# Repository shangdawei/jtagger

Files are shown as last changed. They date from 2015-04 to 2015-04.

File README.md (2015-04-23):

# jtagger?

Well, it's not really just a jtagger, but I've been calling it that. It's also
been christened the Bit Quacker... uh, because it quacks? \*shrug\*

The basis for this design is sort of like the [Bus Blaster](http://dangerousprototypes.com/docs/Bus_Blaster), with a few nice mods. It's smaller (I'm working on V2, which may or may not ever be finished, which will be even smaller), it has an FPGA instead of a CPLD (not only more versatile, but will never be worn out by writes and rewrites), it's 5V-capable, and it can even do up to 13V on one pin, to enable programming microcontrollers with HVP.

The idea is that this can be adapted to program (as close to literally as possible) _any_ serial-programmed logic device, and debugging can be done as well.

In its most basic form, it's compatible with FT2232-compatible JTAG tools, as a simple firmware can be loaded to the FPGA that just passes the [MPSSE](http://www.ftdichip.com/Support/Documents/AppNotes/AN_135_MPSSE_Basics.pdf) signals straight through. The second port on the FT2232 can program the FPGA, so it's self-programming (it does, however, have a flash memory, so it can be preloaded with a firmware to skip this step).

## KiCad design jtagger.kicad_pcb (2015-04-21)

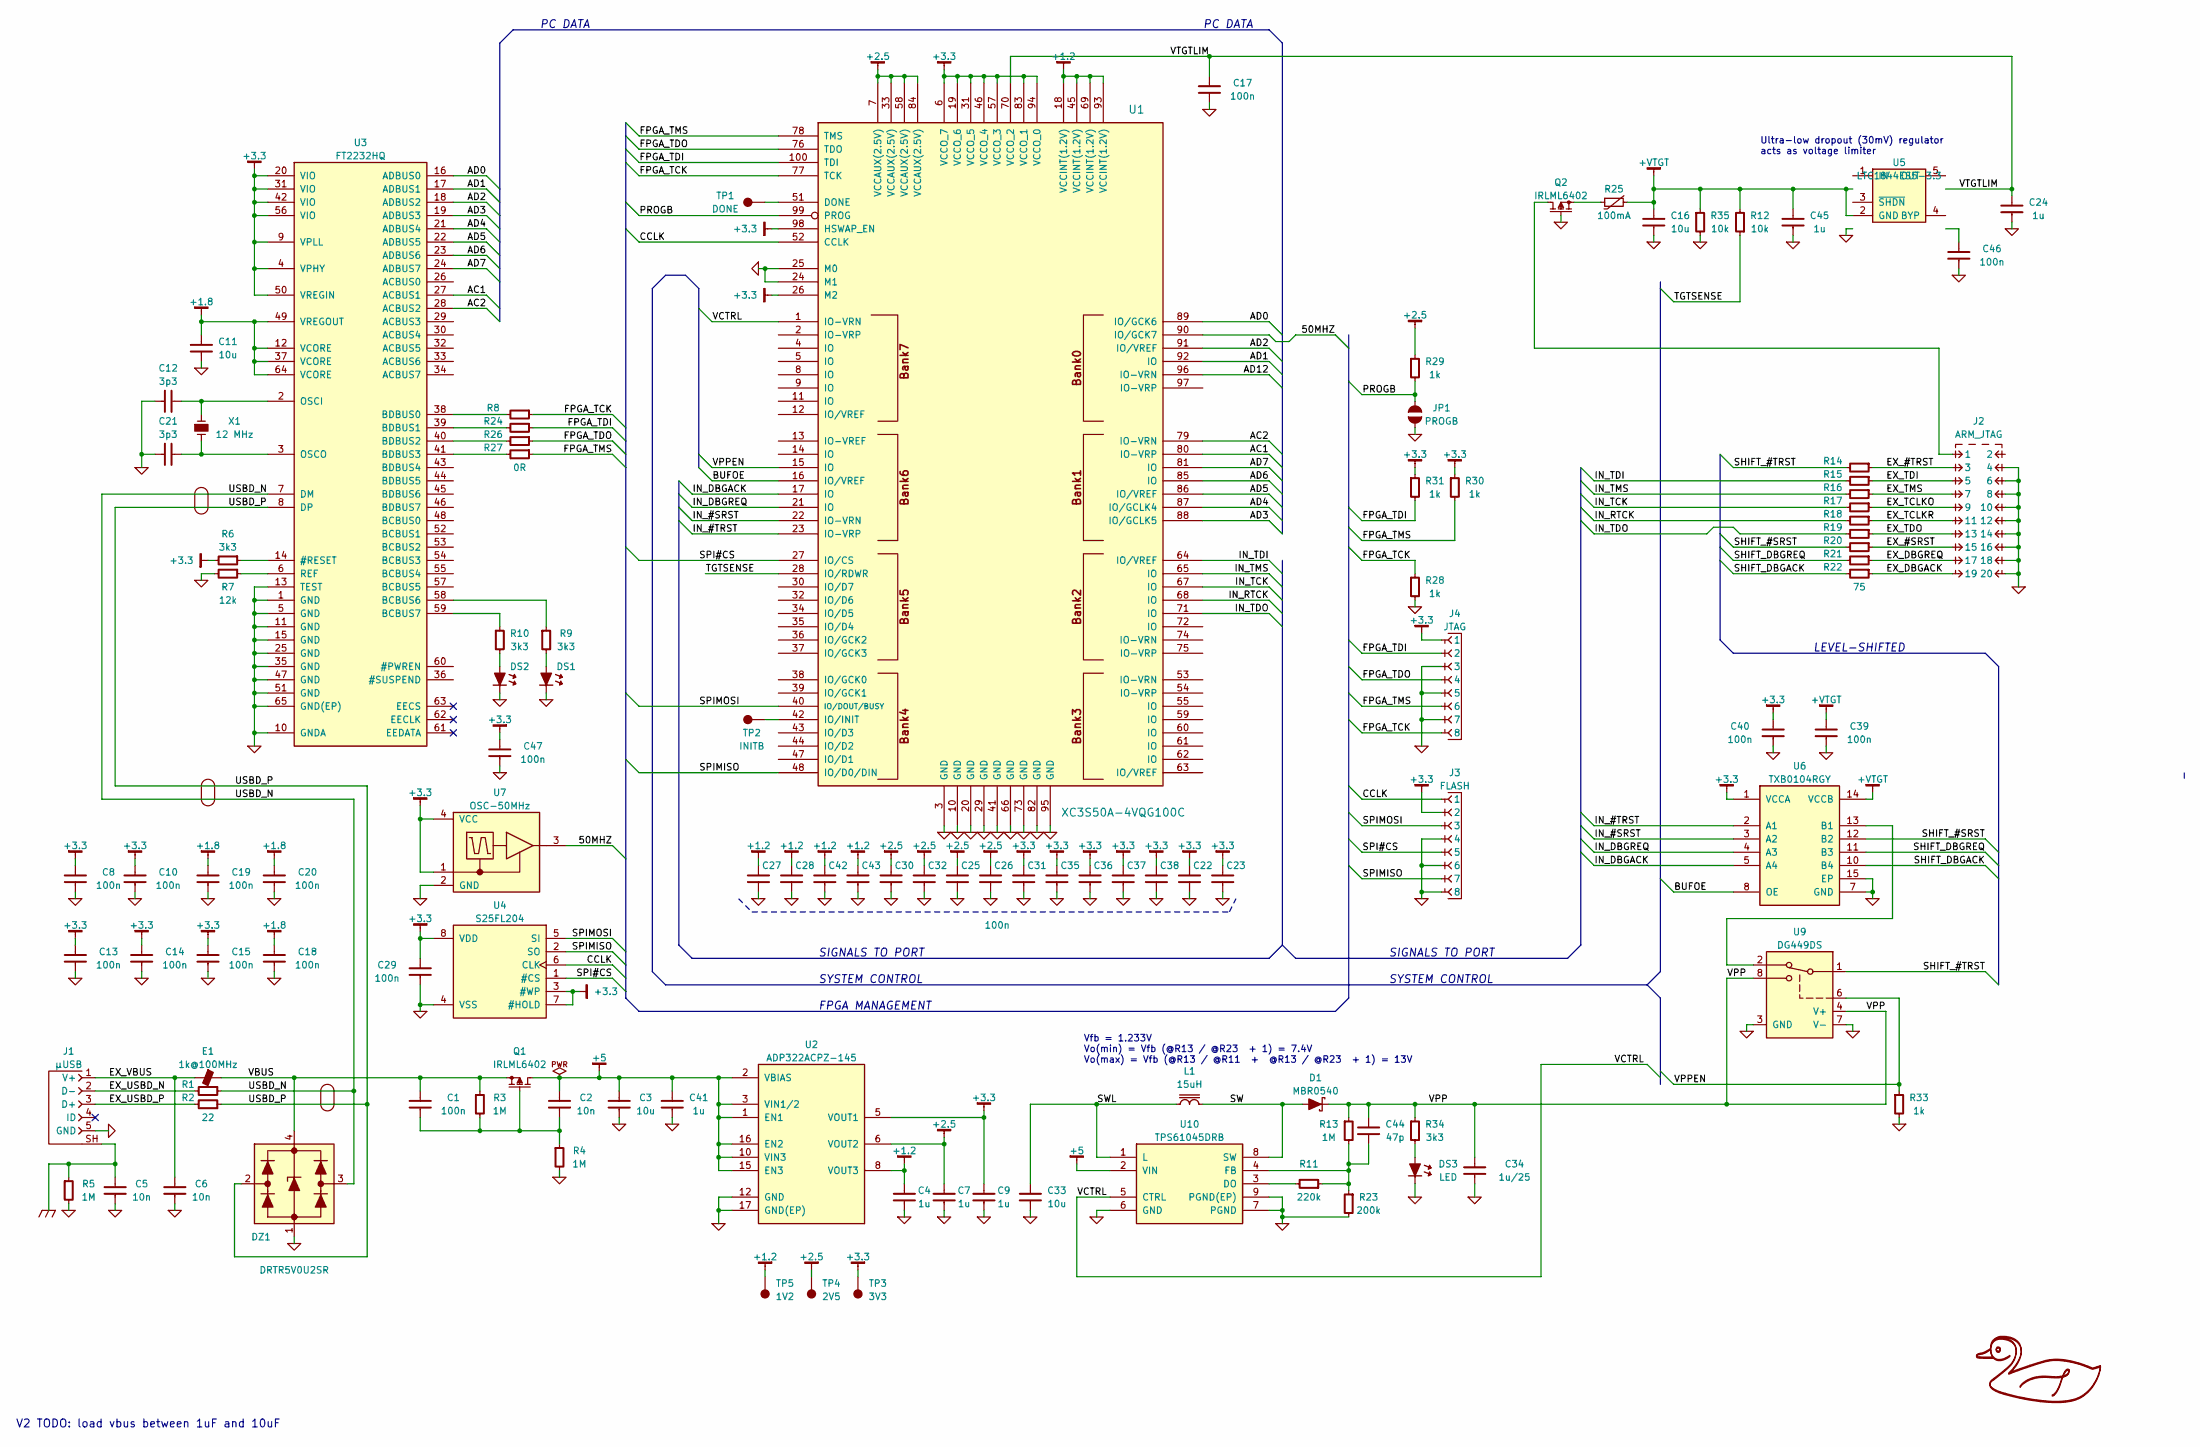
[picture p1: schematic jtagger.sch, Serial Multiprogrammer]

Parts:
C1, C8, C10, C13, C14, C15, C17, C18, C19, C20, C22, C23, C25, C26, C27, C28, C29, C30, C31, C32, C35, C36, C37, C38, C39, C40, C42, C43, C46, C47: 100n; CAPC1005X55
C2, C5, C6: 10n; CAPC1005X55
C3, C11, C16, C33: 10u; CAPC2012X70
C4, C7, C9, C24, C41, C45: 1u; CAPC1608X55
C12, C21: 3p3; CAPC1005X55
C34: 1u/25; CAPC3216X70
C44: 47p; CAPC1005X55
D1: MBR0540; SOD-123
DS1, DS2: LED-0603
DS3: LED; LED-0603
DZ1: DRTR5V0U2SR; SOT-143
E1: 1k@100MHz; INDC1608X95
J1: µUSB; CONN-10118194-0001LF-FCI
J2: ARM_JTAG; CONN-100MIL-M-2x10-SHROUD
J3: FLASH; CONN-MOLEX-52808-0871
J4: JTAG; CONN-MOLEX-52808-0871
JP1: PROGB
L1: 15uH; BOURNS-SRN3015
Q1, Q2: IRLML6402; SOT-23
R1, R2: 22; RESC1005X40
R3, R4, R5, R13: 1M; RESC1005X40
R6, R9, R10, R34: 3k3; RESC1005X40
R7: 12k; RESC1005X40
R8, R24, R26, R27: 0R; RESC1005X40
R11: 220k; RESC1005X40
R12, R35: 10k; RESC1005X40
R14, R15, R16, R17, R18, R19, R20, R21, R22: 75; RESC2012X50
R23: 200k; RESC1005X40
R25: 100mA; RESC2012X50
R28, R29, R30, R31, R33: 1k; RESC1005X40
TP1: DONE; TEST-SMD-SMALL
TP2: INITB; TEST-SMD-SMALL
TP3: 3V3; TEST-SMD-SMALL
TP4: 2V5; TEST-SMD-SMALL
TP5: 1V2; TEST-SMD-SMALL
U1: XC3S50A-4VQG100C; QFP50P1600X1600X100-100
U2: ADP322ACPZ-145; QFN50P300X300X100-17
U3: FT2232HQ; QFN50P900X900X100-65
U4: S25FL204; SOIC127P600X175-8
U5: LTC1844ES5-3.3; SOT-23-5
U6: TXB0104RGY; TEXAS-RGY
U7: OSC-50MHz; SILABS-DFN-SI501-B
U9: DG449DS; SOT-23-8
U10: TPS61045DRB; SON65P300X300X80-9
X1: 12 MHz; XTAL1200X480X460

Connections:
+1.2: C4.1, C27.1, C28.1, C42.1, C43.1, TP5.1, U1.18 (VCCINT(1.2V)), U1.45 (VCCINT(1.2V)), U1.69 (VCCINT(1.2V)), U1.93 (VCCINT(1.2V)), U2.8 (VOUT3)
+1.8: C11.1, C18.1, C19.1, C20.1, U3.12 (VCORE), U3.37 (VCORE), U3.49 (VREGOUT), U3.64 (VCORE)
+2.5: C7.1, C25.1, C26.1, C30.1, C32.1, R29.1, TP4.1, U1.7 (VCCAUX(2.5V)), U1.33 (VCCAUX(2.5V)), U1.58 (VCCAUX(2.5V)), U1.84 (VCCAUX(2.5V)), U2.6 (VOUT2)
+3.3: C8.1, C9.1, C10.1, C13.1, C14.1, C15.1, C22.1, C23.1, C29.1, C31.1, C35.1, C36.1, C37.1, C38.1, C40.1, C47.1, J3.2, J4.1, R6.2, R30.1, R31.1, TP3.1, U1.6 (VCCO_7), U1.19 (VCCO_6), U1.26 (M2), U1.31 (VCCO_5), U1.46 (VCCO_4), U1.57 (VCCO_3), U1.83 (VCCO_1), U1.94 (VCCO_0), U1.98 (HSWAP_EN), U2.5 (VOUT1), U3.4 (VPHY), U3.9 (VPLL), U3.20 (VIO), U3.31 (VIO), U3.42 (VIO), U3.50 (VREGIN), U3.56 (VIO), U4.3 (#WP), U4.7 (#HOLD), U4.8 (VDD), U6.1 (VCCA), U7.1 (OE), U7.4 (VCC)
+5: C2.1, C3.1, C41.1, Q1.3, U2.1 (EN1), U2.2 (VBIAS), U2.3 (VIN1/2), U2.10 (VIN3), U2.15 (EN3), U2.16 (EN2), U10.2 (VIN)
/50MHZ: U1.90 (IO/GCK7), U7.3 (OUT)
/AD0: U1.89 (IO/GCK6), U3.16 (ADBUS0)
/AD1: U1.92 (IO), U3.17 (ADBUS1)
/AD2: U1.91 (IO/VREF), U3.18 (ADBUS2)
/AD3: U1.88 (IO/GCLK5), U3.19 (ADBUS3)
/AD4: U1.87 (IO/GCLK4), U3.21 (ADBUS4)
/AD5: U1.86 (IO/VREF), U3.22 (ADBUS5)
/AD6: U1.85 (IO), U3.23 (ADBUS6)
/AD7: U1.81 (IO), U3.24 (ADBUS7)
/AD8: U3.26 (ACBUS0)
/AD9: U1.80 (IO-VRP), U3.27 (ACBUS1)
/AD10: U1.79 (IO-VRN), U3.28 (ACBUS2)
/AD11: U3.29 (ACBUS3)
/AD12: U1.96 (IO-VRN), U3.30 (ACBUS4)
/AD13: U3.32 (ACBUS5)
/AD14: U3.33 (ACBUS6)
/AD15: U3.34 (ACBUS7)
/BUFOE: U1.16 (IO/VREF), U6.8 (OE)
/CCLK: J3.1, U1.52 (CCLK), U4.6 (CLK)
/DONE: TP1.1, U1.51 (DONE)
/EX_#SRST: J2.15, R20.1
/EX_#TRST: J2.3, R14.1
/EX_DBGACK: J2.19, R22.1
/EX_DBGREQ: J2.17, R21.1
/EX_TCLKO: J2.9, R17.1
/EX_TCLKR: J2.11, R18.1
/EX_TDI: J2.5, R15.1
/EX_TDO: J2.13, R19.1
/EX_TMS: J2.7, R16.1
/EX_USBD_N: J1.2 (D-), R1.2
/EX_USBD_P: J1.3 (D+), R2.2
/EX_VBUS: C6.1, E1.1, J1.1 (V+)
/FPGA_TCK: J4.8, R8.1, R28.1, U1.77 (TCK)
/FPGA_TDI: J4.2, R24.1, R31.2, U1.100 (TDI)
/FPGA_TDO: J4.4, R26.1, U1.76 (TDO)
/FPGA_TMS: J4.6, R27.1, R30.2, U1.78 (TMS)
/IN_#SRST: U1.22 (IO-VRN), U6.3 (A2)
/IN_#TRST: U1.23 (IO-VRP), U6.2 (A1)
/IN_DBGACK: U1.17 (IO), U6.5 (A4)
/IN_DBGREQ: U1.21 (IO), U6.4 (A3)
/IN_RTCK: R18.2, U1.68 (IO)
/IN_TCK: R17.2, U1.67 (IO)
/IN_TDI: R15.2, U1.64 (IO/VREF)
/IN_TDO: R19.2, U1.71 (IO)
/IN_TMS: R16.2, U1.65 (IO)
/SPI#CS: J3.5, U1.27 (IO/CS), U4.1 (#CS)
/SPIMISO: J3.7, U1.48 (IO/D0/DIN), U4.2 (SO)
/SPIMOSI: J3.3, U1.40 (IO/DOUT/BUSY), U4.5 (SI)
/SW: D1.2, L1.1, U10.8 (SW)
/SWL: C33.1, L1.2, U10.1 (L)
/TGTSENSE: R12.1, U1.28 (IO/RDWR)
/USBD_N: DZ1.3, R1.1, U3.7 (DM)
/USBD_P: DZ1.2, R2.1, U3.8 (DP)
/VBUS: C1.1, DZ1.4, E1.2, Q1.2, R3.1
/VCTRL: U1.1 (IO-VRN), U10.5 (CTRL)
/VPP: C34.1, C44.1, D1.1, R13.1, R34.1, U9.4 (V+), U9.8
/VPPEN: R33.1, U1.15 (IO), U9.6
/VTGTLIM: C17.1, C24.1, U1.70 (VCCO_2), U5.5 (OUT)
CGND: C5.1, J1.SH (SHIELD), R5.1
unnamed: C1.2, C2.2, Q1.1, R3.2, R4.1
unnamed: C12.1, U3.2 (OSCI), X1.1
unnamed: C21.1, U3.3 (OSCO), X1.2
unnamed: C44.2, R11.1, R13.2, R23.1, U10.4 (FB)
unnamed: C46.1, U5.4 (BYP)
unnamed: DS1.2, R9.2
unnamed: DS2.2, R10.2
unnamed: DS3.2, R34.2
unnamed: J2.1, Q2.3
unnamed: JP1.1, R29.2, U1.99 (PROG)
unnamed: Q2.2, R25.1
unnamed: R6.1, U3.14 (#RESET)
unnamed: R7.1, U3.6 (REF)
unnamed: R8.2, U3.38 (BDBUS0)
unnamed: R9.1, U3.58 (BCBUS6)
unnamed: R10.1, U3.59 (BCBUS7)
unnamed: R11.2, U10.3 (DO)
unnamed: R14.2, U9.1
unnamed: R20.2, U6.12 (B2)
unnamed: R21.2, U6.11 (B3)
unnamed: R22.2, U6.10 (B4)
unnamed: R24.2, U3.39 (BDBUS1)
unnamed: R26.2, U3.40 (BDBUS2)
unnamed: R27.2, U3.41 (BDBUS3)
unnamed: TP2.1, U1.42 (IO/INIT)
unnamed: U6.13 (B1), U9.2

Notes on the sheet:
Vfb = 1.233V Vo(min) = Vfb (@R13 / @R23 + 1) = 7.4V Vo(max) = Vfb (@R13 / @R11 + @R13 / @R23 + 1) = 13V
SIGNALS TO PORT
SYSTEM CONTROL
FPGA MANAGEMENT
PC DATA
LEVEL-SHIFTED
Ultra-low dropout (30mV) regulator acts as voltage limiter
V2 TODO: load vbus between 1uF and 10uF

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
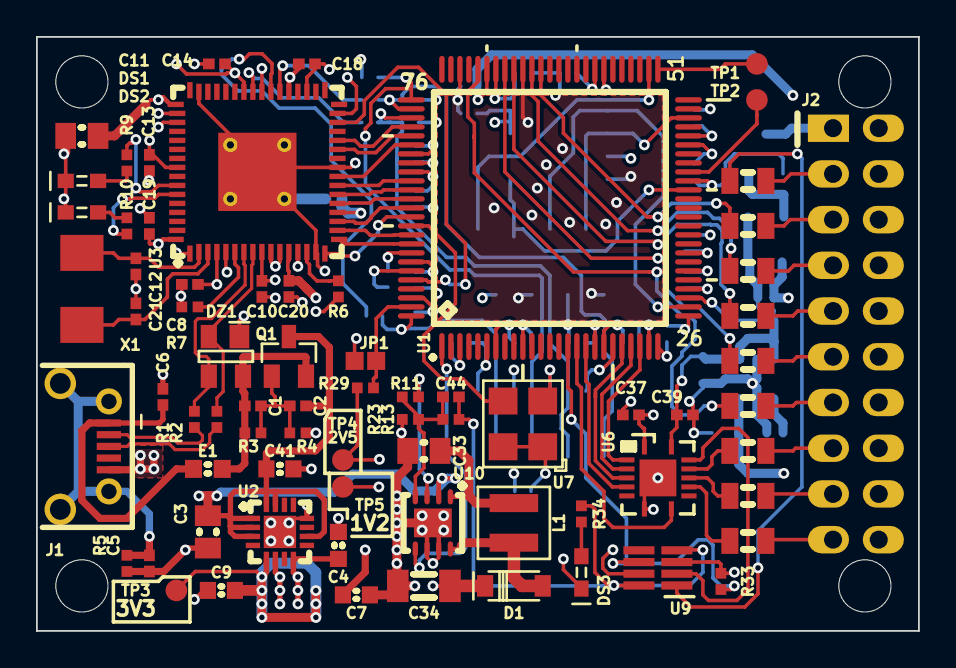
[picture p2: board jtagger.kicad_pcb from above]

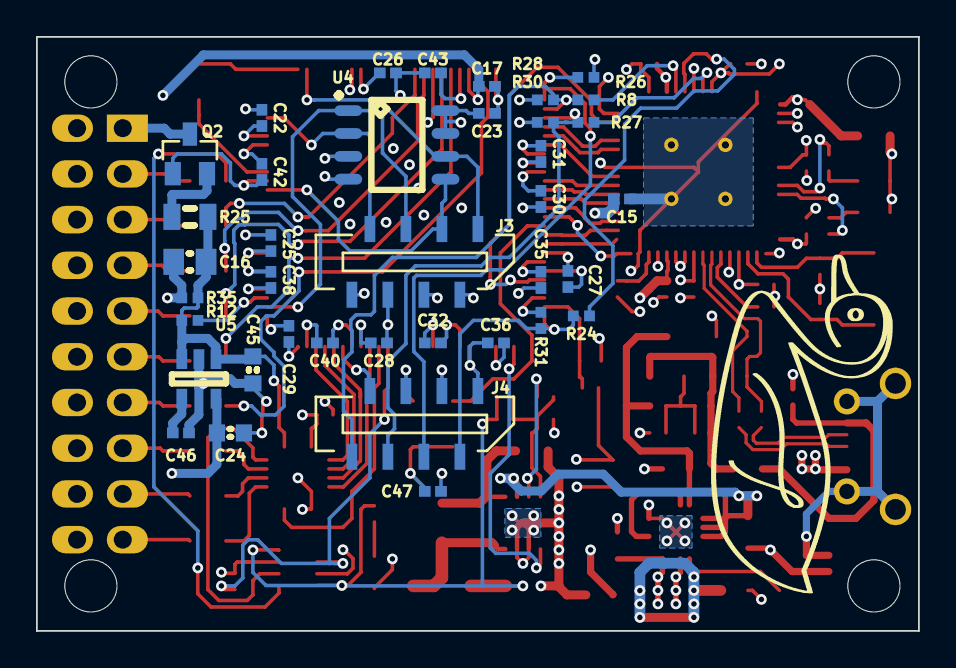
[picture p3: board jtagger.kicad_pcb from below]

Board: 4 copper layers, 49.0 x 33.0 mm, 110 parts (38 on the bottom side), 87 nets.

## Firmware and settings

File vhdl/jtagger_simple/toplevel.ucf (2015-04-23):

NET "bufoe" LOC = P16;
NET "clk" LOC = P90;

# PlanAhead Generated physical constraints

NET "ftdi_ac1" LOC = P80;
NET "ftdi_ac2" LOC = P79;
NET "ftdi_ad0" LOC = P89;
NET "ftdi_ad1" LOC = P92;
NET "ftdi_ad2" LOC = P91;
NET "ftdi_ad3" LOC = P88;
NET "ftdi_ad4" LOC = P87;
NET "ftdi_ad5" LOC = P86;
NET "ftdi_ad6" LOC = P85;
NET "ftdi_ad7" LOC = P81;
NET "iopin_3" LOC = P23;
NET "iopin_5" LOC = P64;
NET "iopin_7" LOC = P65;
NET "iopin_9" LOC = P67;
NET "iopin_11" LOC = P68;
NET "iopin_13" LOC = P71;
NET "iopin_15" LOC = P22;
NET "iopin_17" LOC = P21;
NET "iopin_19" LOC = P17;
NET "tgtsense" LOC = P28;
NET "vctrl" LOC = P1;
NET "vppen" LOC = P15;

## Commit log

2015-04-09 Version submitted to fab
    [gerb.GBL, gerb.GBO, gerb.GBS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]
2015-04-10 Schematic stuff
    [jtagger.sch]
2015-04-21 Fix PCB bug: FT2232 thermal pad too big
    [jtagger.kicad_pcb, jtagger.sch]
